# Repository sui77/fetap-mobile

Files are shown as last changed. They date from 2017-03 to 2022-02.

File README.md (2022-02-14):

# fetap-mobile
Turn your old Fernsprechtischapparat FeTAp 611 (or any other rotary dial phone) into a mobile phone. 

## Bom
 - FeTAp 611 rotary dial phone
 - Arduino Pro Mini
 - sim800l GSM module
 - TP4056 lithium battery charger module with protection
 - 18560 type lithium battery
 - 3V-35V step up boost converter
 - L293D H-Bridge

## Software
 - [Rotary-Dial](https://github.com/markfickett/Rotary-Dial) library
 - Arduino sketch from this repository
 
##

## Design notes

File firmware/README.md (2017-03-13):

# rotary-sim800
Turn your old rotary dial phone into a cell phone. (WIP, not stable yet)

## Hardware
 - A old rotary dial phone (for example a german FeTAp 611)
 - Arduino board
 - sim800 GSM module
 - TP4056 lithium battery charger module with protection
 - 18560 type lithium battery
 - 3V-35V step up boost converter
 - L293D H-Bridge

## Software
 - [Rotary-Dial](https://github.com/markfickett/Rotary-Dial) library
 - Arduino sketch from this repository

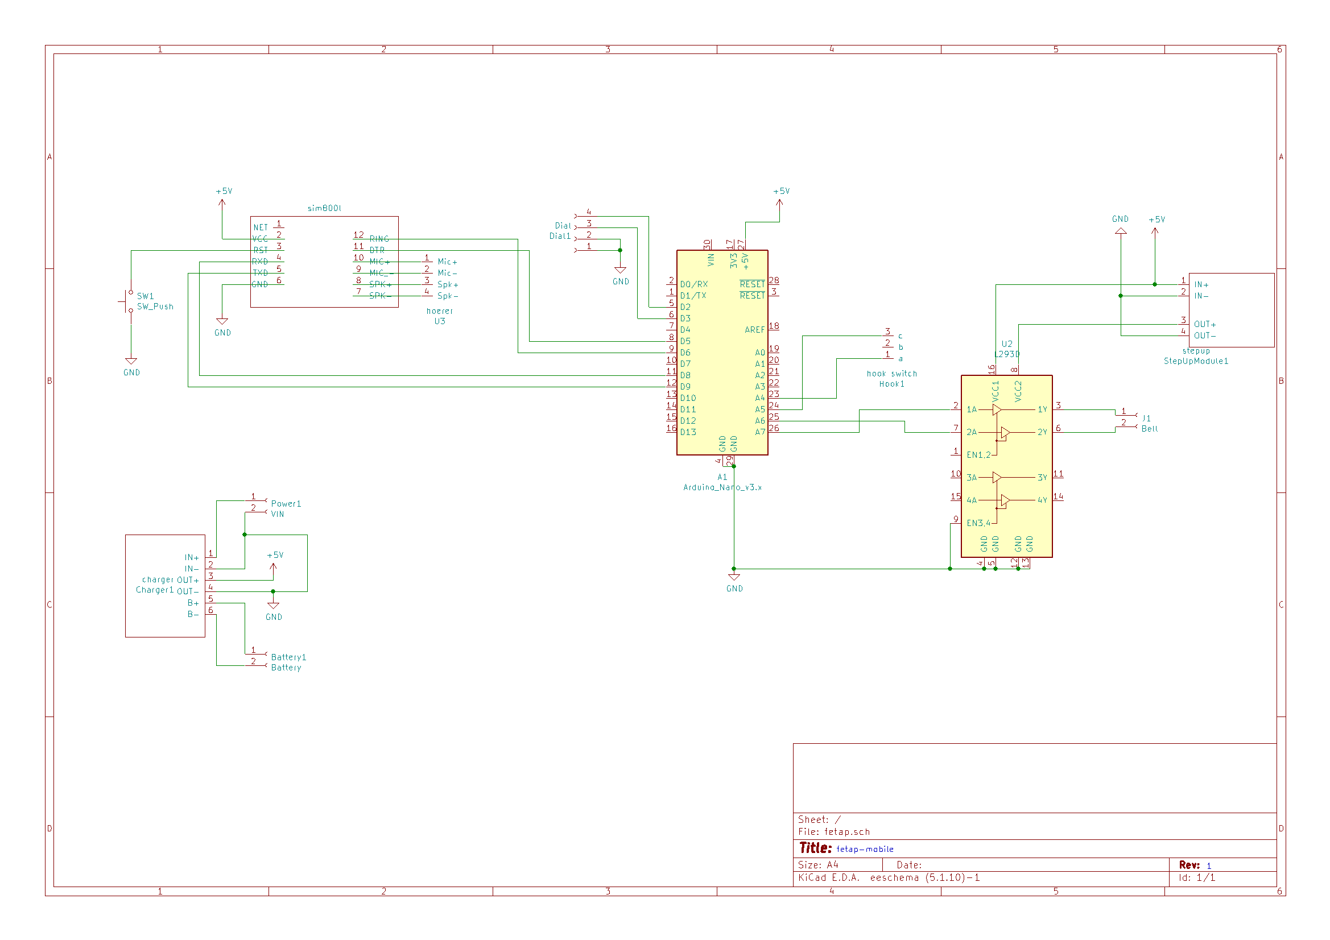
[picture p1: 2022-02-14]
docs/schema.png

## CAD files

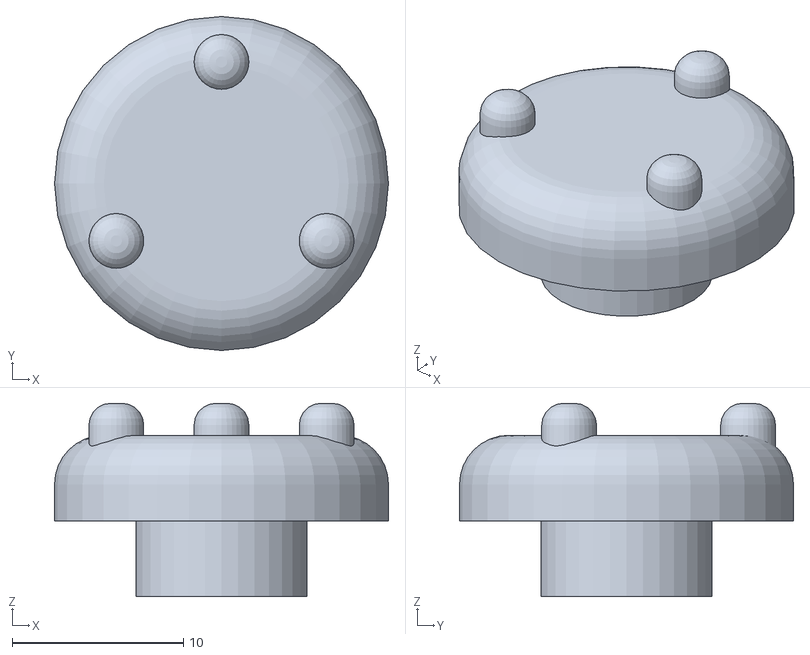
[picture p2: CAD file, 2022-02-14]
3d/device-foot.stl
19.5 x 19.5 x 11.3

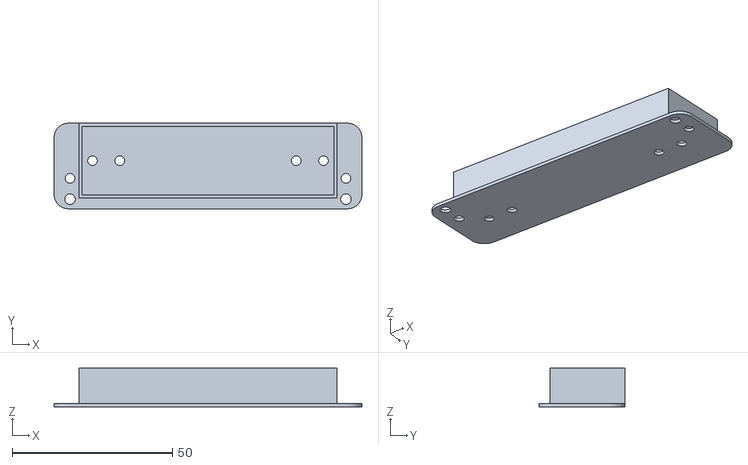
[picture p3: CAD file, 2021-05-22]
3d/18650-battery-holder.stl
96.0 x 26.7 x 12.0

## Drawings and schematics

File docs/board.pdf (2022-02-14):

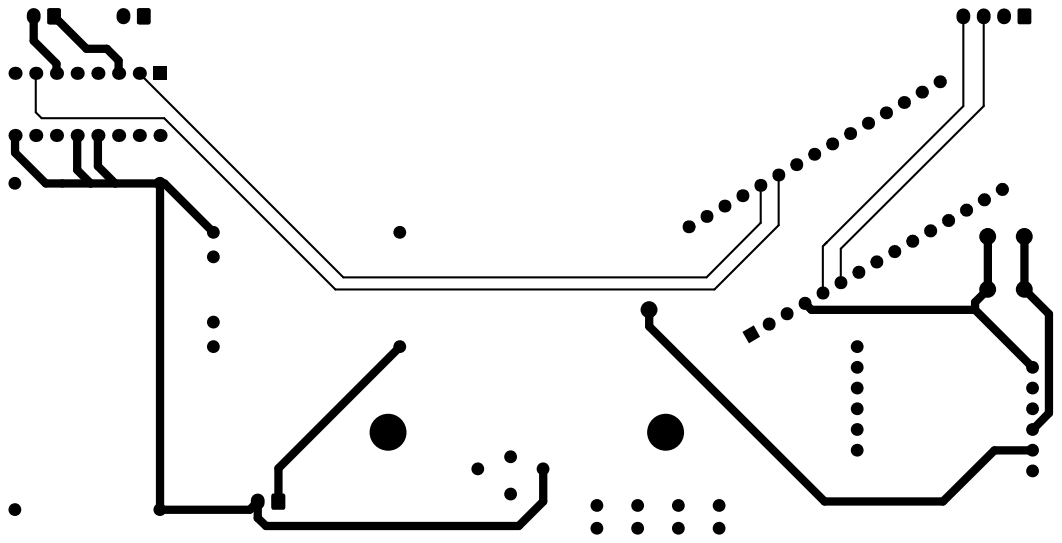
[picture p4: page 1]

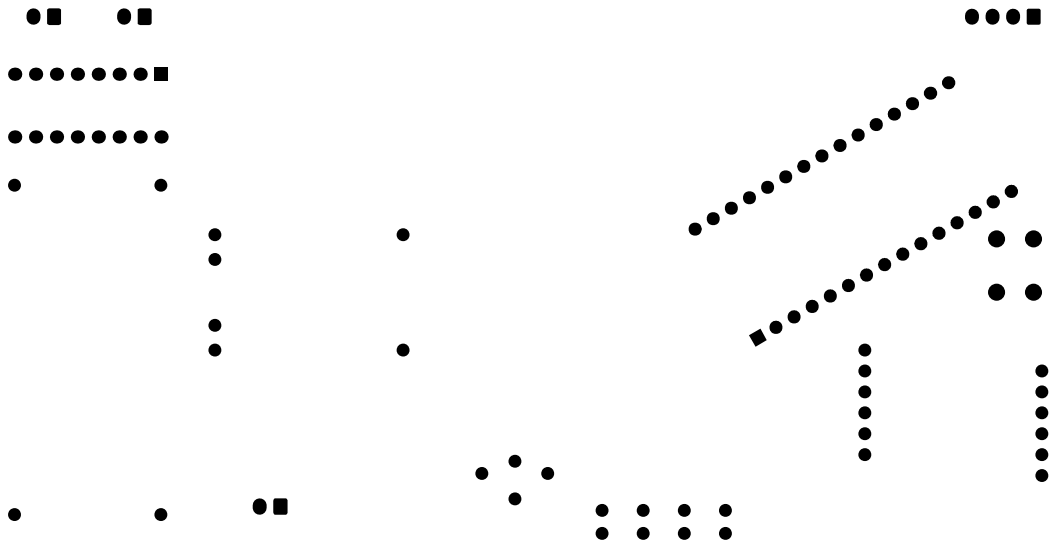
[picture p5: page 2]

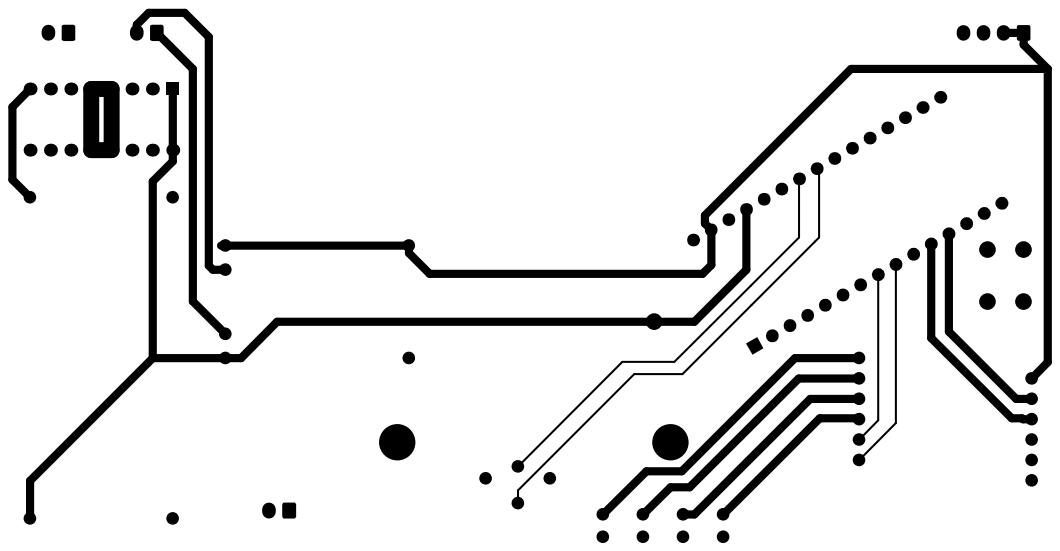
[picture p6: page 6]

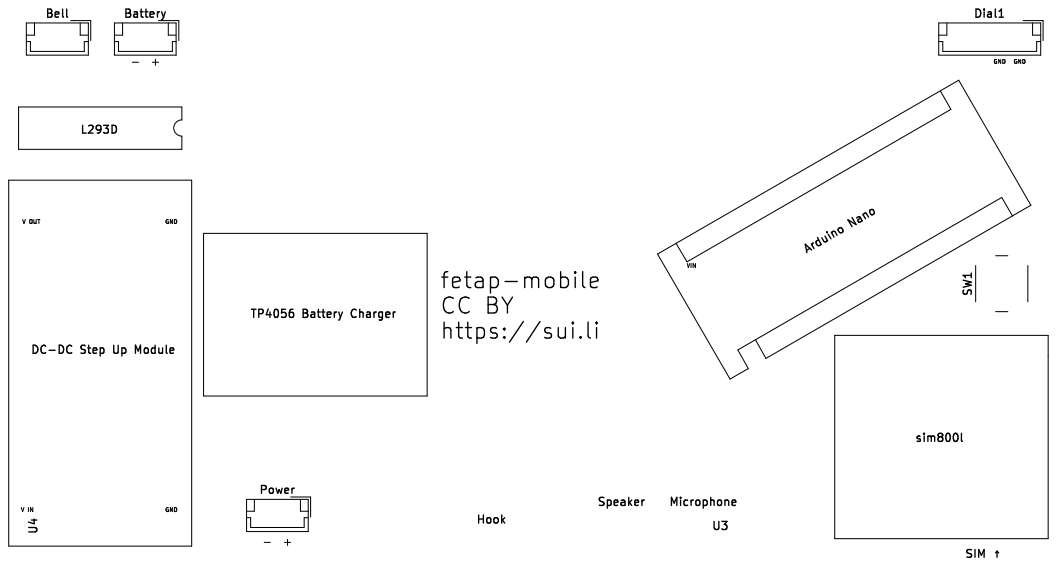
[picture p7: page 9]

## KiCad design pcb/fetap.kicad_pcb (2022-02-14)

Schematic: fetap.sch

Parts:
A1: Arduino_Nano_v3.x; Arduino_Nano
Battery1: Battery; JST_EH_B2B-EH-A_1x02_P2.50mm_Vertical
Charger1: charger
Dial1: Dial; JST_EH_B4B-EH-A_1x04_P2.50mm_Vertical
Hook1: hook switch; cradleswitch
J1: Bell; JST_EH_B2B-EH-A_1x02_P2.50mm_Vertical
Power1: VIN; JST_EH_B2B-EH-A_1x02_P2.50mm_Vertical
SW1: SW_Push; SW_PUSH_6mm
StepUpModule1: stepup
U2: L293D; DIP-16_W7.62mm
U3: hoerer; suat
sim800l1: sim800l

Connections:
+5V: A1.27, Charger1.3 (OUT+), StepUpModule1.1 (IN+), U2.16 (VCC1), sim800l1.2 (VCC)
GND: A1.4, A1.29, Charger1.2 (IN-), Charger1.4 (OUT-), Dial1.1, Dial1.2, Power1.2, SW1.1, StepUpModule1.2 (IN-), StepUpModule1.4 (OUT-), U2.4 (GND), U2.5 (GND), U2.9 (EN3,4), U2.12 (GND), U2.13 (GND), sim800l1.6 (GND)
unnamed: A1.6, Dial1.4
unnamed: A1.7, Dial1.3
unnamed: A1.9, sim800l1.11 (DTR)
unnamed: A1.10, sim800l1.12 (RING)
unnamed: A1.12, sim800l1.4 (RXD)
unnamed: A1.23, Hook1.1 (a)
unnamed: A1.24, Hook1.3 (c)
unnamed: A1.25, U2.7 (2A)
unnamed: A1.26, U2.2 (1A)
unnamed: Battery1.1, Charger1.5 (B+)
unnamed: Battery1.2, Charger1.6 (B-)
unnamed: Charger1.1 (IN+), Power1.1
unnamed: J1.1, U2.3 (1Y)
unnamed: J1.2, U2.6 (2Y)
unnamed: SW1.2, sim800l1.3 (RST)
unnamed: StepUpModule1.3 (OUT+), U2.8 (VCC2)
unnamed: U3.1 (Mic+), sim800l1.10 (MIC+)
unnamed: U3.2 (Mic-), sim800l1.9 (MIC_-)
unnamed: U3.3 (Spk+), sim800l1.8 (SPK+)
unnamed: U3.4 (Spk-), sim800l1.7 (SPK-)

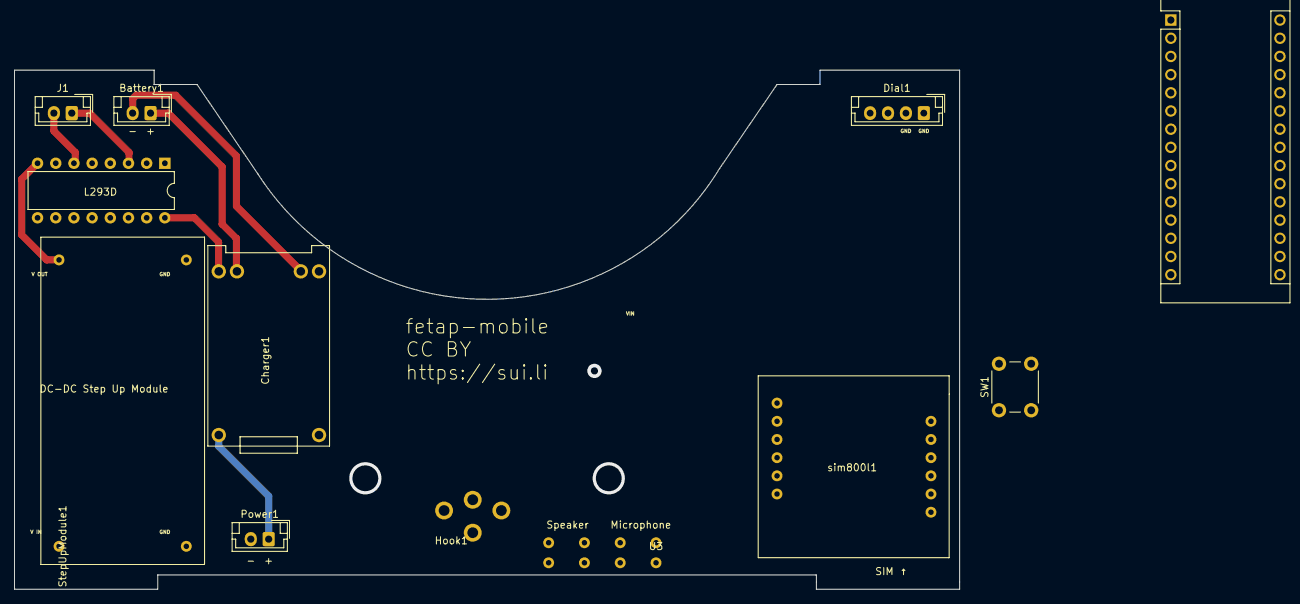
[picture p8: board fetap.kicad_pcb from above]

Board: 2 copper layers, 132.0 x 72.5 mm, 12 parts (0 on the bottom side), 22 nets.

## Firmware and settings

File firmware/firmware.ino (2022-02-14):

#include <RotaryDialer.h>

// Rotary dial wheel
// at least in my FeTAP 611 yellow + brown are GND
#define PIN_ROTARY_READY	2   // white
#define PIN_ROTARY_PULSE	3   // green

// Hook - connect it to GND + this pin
#define PIN_HOOK A1

// H-Bridge input for ringer goes to
#define PIN_RINGER1 A2
#define PIN_RINGER2 A3

// RX + TX @sim800
#define PIN_SIM800_RX 8
#define PIN_SIM800_TX 9


#define STATE_OFF 1
#define STATE_READY_TO_DIAL 2
#define STATE_RINGING 3
#define STATE_CALL 4
#define STATE_INPUT_SPEED_DIAL_SLOT 5
#define STATE_INPUT_SPEED_DIAL_NUMBER 6


int currentState  = STATE_OFF;
int previousState = STATE_OFF;

char readbuffer[100];
int readbufferP = 0;

char phonenumber[20];
int phonenumberP = 0;
double lastNumberMillis = 0;
bool firstNumberDialed = false;
int speedDial = 0;

double lastRingingMillis = 0;

RotaryDialer dialer = RotaryDialer(PIN_ROTARY_READY, PIN_ROTARY_PULSE);

  
void setup() {
  Serial.begin(9600);
  fetap611_init();
  sim800_init();
  dialer.setup();
  Serial.println("Ready");

  for (int i = 1; i<10; i++) {
    Serial.print("Speed Dial #"); Serial.print(i); Serial.print(": "); Serial.println(getNumber(i));
  }

}


bool numberInput(int inputTimeMs) {

    if (!fetap_offhook()) {
        currentState = STATE_OFF;
        toneOff();
        sim800_hangUp();
        Serial.println("OFF");
    }
  
    if (dialer.update()) {
        int dialedNumber = dialer.getNextNumber();
        Serial.println(dialedNumber);
        phonenumber[phonenumberP] = 48 + dialedNumber;
        phonenumber[phonenumberP];
        phonenumber[phonenumberP+1] = 0;
        lastNumberMillis = millis();
        
        phonenumberP++;
        if (phonenumberP > 18) {
          phonenumberP = 0;
          toneError();
        }
    }

    if (phonenumberP > 0 && millis() > lastNumberMillis + inputTimeMs) {
        Serial.print("Input: ");
        Serial.print(currentState);
        Serial.println( phonenumber);
        return true;
    } 
    
    return false;
}

void loop() {

  if (previousState != currentState) {
    Serial.print("State was changed to ");   
    Serial.println(currentState);
  }
  previousState = currentState;
 
  switch (currentState) {
    
    case STATE_OFF:
      phonenumberP = 0;
      firstNumberDialed = 0;
      if (fetap_offhook()) {
        toneFreizeichen();
        currentState = STATE_READY_TO_DIAL;
      }
    break;

    case STATE_READY_TO_DIAL:

      // turn off dial tone if rotary wheel was moved
      if (!firstNumberDialed && digitalRead( PIN_ROTARY_READY ) == 0) {
        firstNumberDialed = true;
        toneOff();
      }

      if (numberInput(4000)) {
        if (phonenumber[1] == 0) {
          if (phonenumber[0] == '0') {
            phonenumberP = 0;
            firstNumberDialed = 0;
            playSound("ansage1");
            currentState = STATE_INPUT_SPEED_DIAL_SLOT;
          } else {
            // speed dial
            currentState = STATE_CALL;
            String sNumber = getNumber(phonenumber[0]-48);
            Serial.print("SpeedDial: ");
            Serial.println(sNumber);
            sim800_call(sNumber);
          }
        } else {
            currentState = STATE_CALL;
            sim800_call(phonenumber);
        }
      }
      
  
    break;

    case STATE_INPUT_SPEED_DIAL_SLOT:
      
      if (numberInput(0)) {
          speedDial = phonenumber[0]-48;
          phonenumberP = 0;
          firstNumberDialed = 0;
          currentState = STATE_INPUT_SPEED_DIAL_NUMBER;
          playSound("ansage3");  
      }
    break;

    case STATE_INPUT_SPEED_DIAL_NUMBER:
      
      if (numberInput(4000)) {
            setNumber(speedDial, phonenumber);
        
            playSound("ansage7"); delay(2000);
            for (int i = 0; i<phonenumberP; i++) {
              playSound(String(phonenumber[i])); delay(1000);
            }
            playSound("ansage6"); delay(2000);
            playSound(String(speedDial)); delay(1000);         
            playSound("ansage5"); delay(2000);
            
            phonenumberP = 0;
            firstNumberDialed = 0;
            currentState = STATE_OFF;
      }
    break;


    case STATE_RINGING:
      
      if (fetap_offhook()) {
        sim800_answerIncomingCall();
        currentState = STATE_CALL;
      } else if (millis() > lastRingingMillis + 5000) {
        currentState = STATE_OFF;
      }
      
    break;

    case STATE_CALL:
      if (!fetap_offhook()) {
        sim800_hangUp();
        currentState = STATE_OFF;
      }    
    break;
  }
 
  
  if (sim800_available()) { 
    Serial.print("From sim800: ");
    Serial.println(readbuffer);
    if (strcmp(readbuffer, "BUSY")  == 0 && currentState == STATE_CALL) {
          noLine();
    } else if (strcmp(readbuffer, "RING")  == 0 && (currentState == STATE_OFF || currentState == STATE_RINGING)) {
          ring();
          currentState = STATE_RINGING;
          lastRingingMillis = millis();
    } else if (strcmp(readbuffer, "NO DIALTONE") == 0 && currentState != STATE_OFF) {
          toneError();
    }
  } 

  if (Serial.available()) {
    char b = Serial.read();
    if (b!=0) {
      sim800_print(b);
      Serial.print(b);
    }
  }

 
}

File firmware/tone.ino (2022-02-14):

void toneFreizeichen() {
  sim800.println("AT+SIMTONE=1,425,25500,0,500000");
}

void toneRinging() {
  sim800.println("AT+SIMTONE=1,425,1000,3500,500000");
}

void noLine() {
  sim800.println("AT+SIMTONE=1,425,240,240,500000");
}

void keinAnschluss() {
  toneError();
  delay(1000);
  sim800.println("AT+CREC=4,C:\\keinanschluss.amr,0,1");
}

void inputTone() {
  sim800.println("AT+SIMTONEX=1,50000,425,400,25500,10,0");
}

void toneOff() {
  sim800.println("AT+SIMTONE=0");
  Serial.println("tone off");
}

void toneInfo(int n) {
  sim800.print("AT+SIMTONE=1,200,200,100,");
  sim800.print( n*300 );
  sim800.println();
}

void playSound(String file) {
  Serial.println("playing");
  sim800.print("AT+CREC=4,C:\\User\\");
  sim800.print(file);
  sim800.println(".amr,0,1");
}


void toneError() {
    sim800.println("AT+SIMTONE=1,950,25500,0,330");
    delay(330);
    sim800.println("AT+SIMTONE=1,1400,25500,0,330");
    delay(330);
    sim800.println("AT+SIMTONE=1,1800,25500,0,330");
    delay(330);
    toneOff();
}

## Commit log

2021-05-15 adding pcb
    [fetap-B_Cu.gbr, fetap-B_Mask.gbr, fetap-B_Paste.gbr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]
2021-05-22 battery holder
    [18650-battery-holder.stl]

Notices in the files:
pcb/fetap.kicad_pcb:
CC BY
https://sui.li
